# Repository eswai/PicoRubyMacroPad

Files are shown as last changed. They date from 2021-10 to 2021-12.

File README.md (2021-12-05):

# PicoRuby Macropad

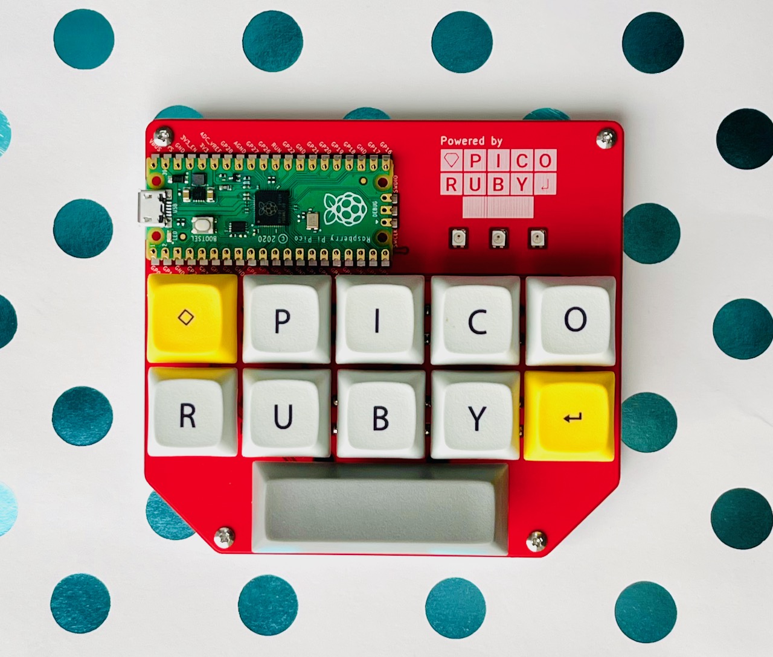
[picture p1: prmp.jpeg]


#  BOM

|Name | Part number|Quantity|
|---|-----|-----|
| MCU | Raspberry Pi Pico | 1|
| Pin header | 20pin | 2|
| PCB | PicoRubyMacroPad_PCB | 1|
| Bottom plate | PicoRubyMacroPad_Plate | 1|
| MX-compaible key switch | 5pins | 11|
| Diode | 1N4148 TH or SMD  | 11|
| Stand-off | M2 L5.5mm or longer | 4|
| Screw | M2 L4mm | 8|
| Keycap | 1U | 10|
| Keycap | 2.75U | 1|
| PCB Stabilizer | 2U | 1|
| LED | SK6812MINI-E | 3|
| Adhesive rubber feet | Dia.9mm or smaller | 4|

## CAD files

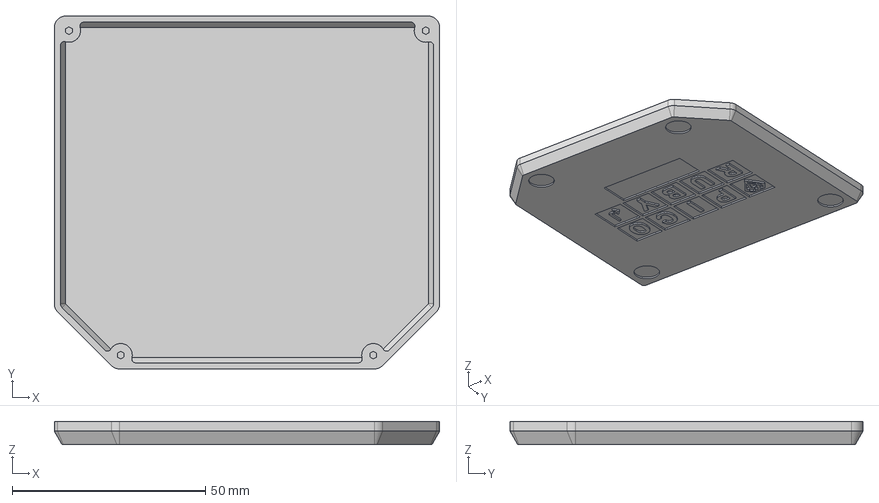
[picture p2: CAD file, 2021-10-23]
PicoRubyMacroPad_case.step
99.8 x 91.4 x 6.00 mm

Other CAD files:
PicoRubyMacroPad_case.f3z

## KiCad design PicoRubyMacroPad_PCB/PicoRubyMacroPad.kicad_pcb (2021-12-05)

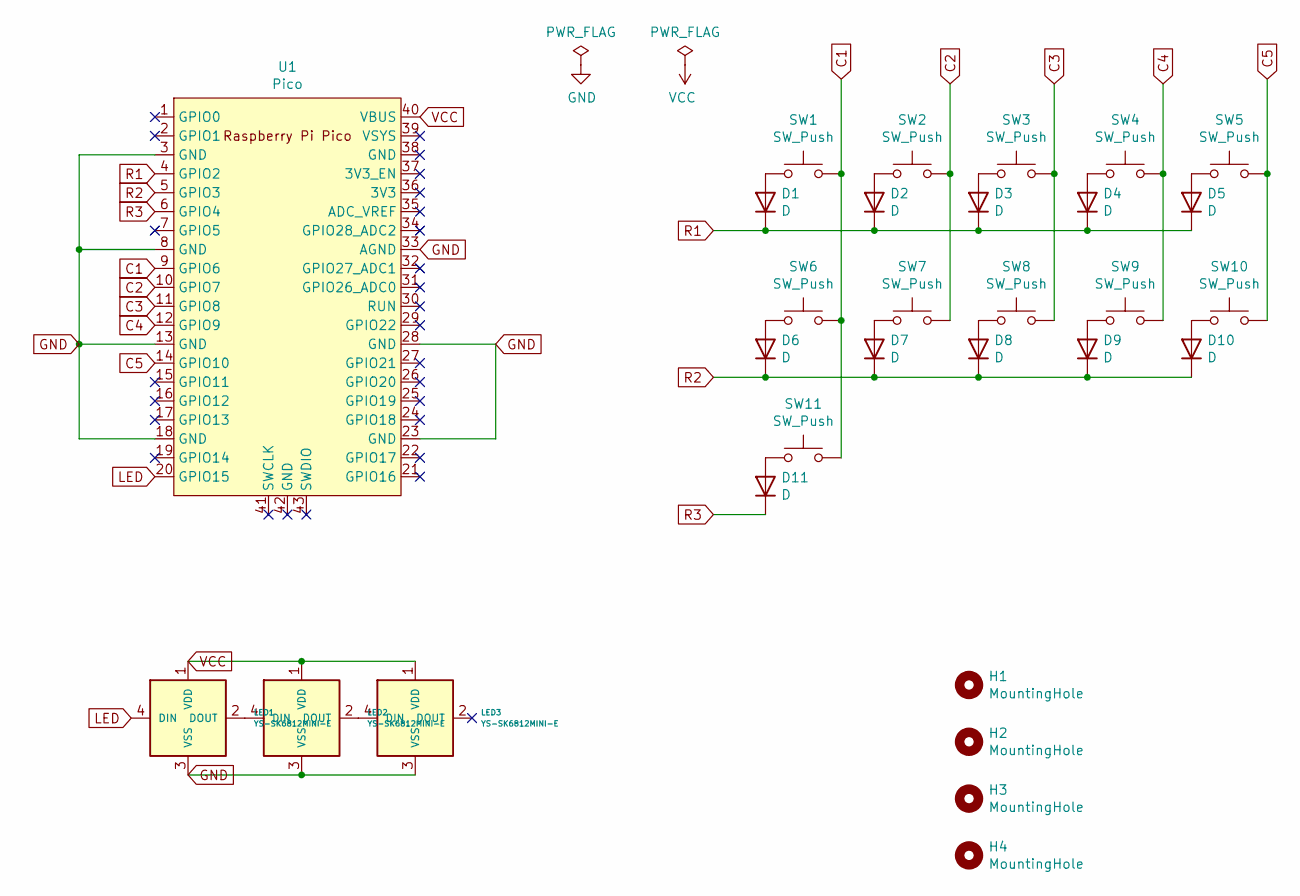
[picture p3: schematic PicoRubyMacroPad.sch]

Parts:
D1, D2, D3, D4, D5, D6, D7, D8, D9, D10, D11: D; D3_TH_SMD_v2
H1, H2, H3, H4: MountingHole; MountingHole_2.2mm_M2
LED1, LED2, LED3: YS-SK6812MINI-E
SW1, SW2, SW3, SW4, SW5, SW6, SW7, SW8, SW9, SW10: SW_Push; MXOnly-1U-NoLED
SW11: SW_Push; MXOnly-2.75U-ReversedStabilizers-NoLED
U1: Pico; RPi_Pico_SMD_TH

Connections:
C1: SW1.2, SW6.2, SW11.2, U1.9 (GPIO6)
C2: SW2.2, SW7.2, U1.10 (GPIO7)
C3: SW3.2, SW8.2, U1.11 (GPIO8)
C4: SW4.2, SW9.2, U1.12 (GPIO9)
C5: SW5.2, SW10.2, U1.14 (GPIO10)
GND: LED1.3 (VSS), LED2.3 (VSS), LED3.3 (VSS), U1.3 (GND), U1.8 (GND), U1.13 (GND), U1.18 (GND), U1.23 (GND), U1.28 (GND), U1.33 (AGND)
LED: LED1.4 (DIN), U1.20 (GPIO15)
unnamed: D1.2 (A), SW1.1
unnamed: D2.2 (A), SW2.1
unnamed: D3.2 (A), SW3.1
unnamed: D4.2 (A), SW4.1
unnamed: D5.2 (A), SW5.1
unnamed: D6.2 (A), SW6.1
unnamed: D7.2 (A), SW7.1
unnamed: D8.2 (A), SW8.1
unnamed: D9.2 (A), SW9.1
unnamed: D10.2 (A), SW10.1
unnamed: D11.2 (A), SW11.1
unnamed: LED1.2 (DOUT), LED2.4 (DIN)
unnamed: LED2.2 (DOUT), LED3.4 (DIN)
R1: D1.1 (K), D2.1 (K), D3.1 (K), D4.1 (K), D5.1 (K), U1.4 (GPIO2)
R2: D6.1 (K), D7.1 (K), D8.1 (K), D9.1 (K), D10.1 (K), U1.5 (GPIO3)
R3: D11.1 (K), U1.6 (GPIO4)
VCC: LED1.1 (VDD), LED2.1 (VDD), LED3.1 (VDD), U1.40 (VBUS)

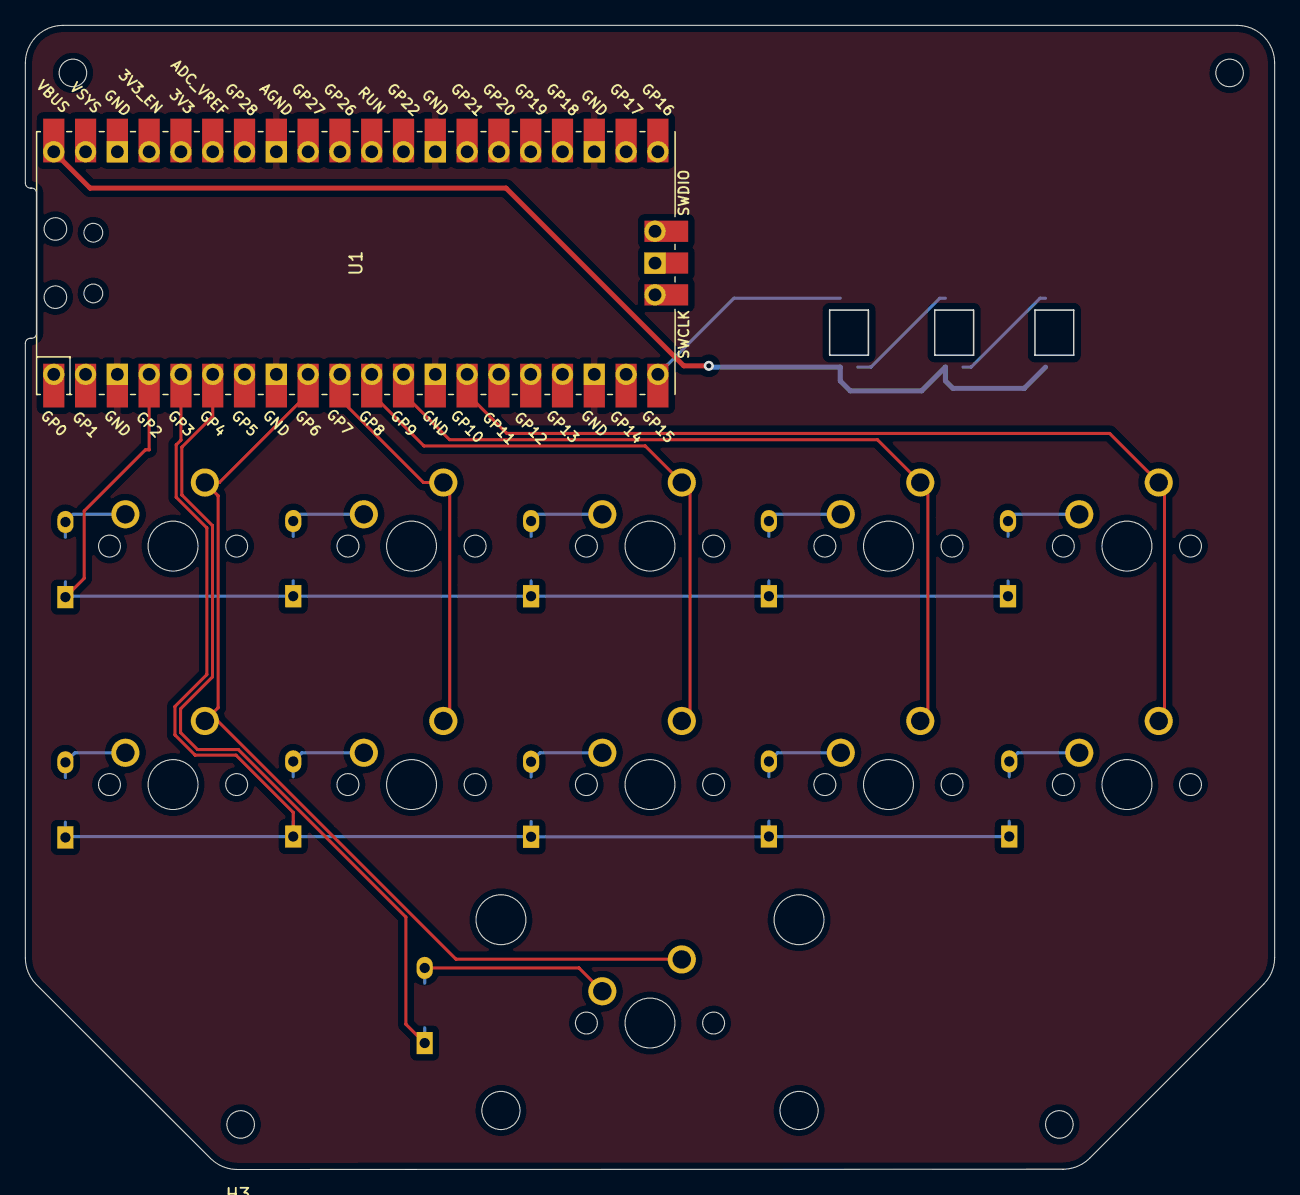
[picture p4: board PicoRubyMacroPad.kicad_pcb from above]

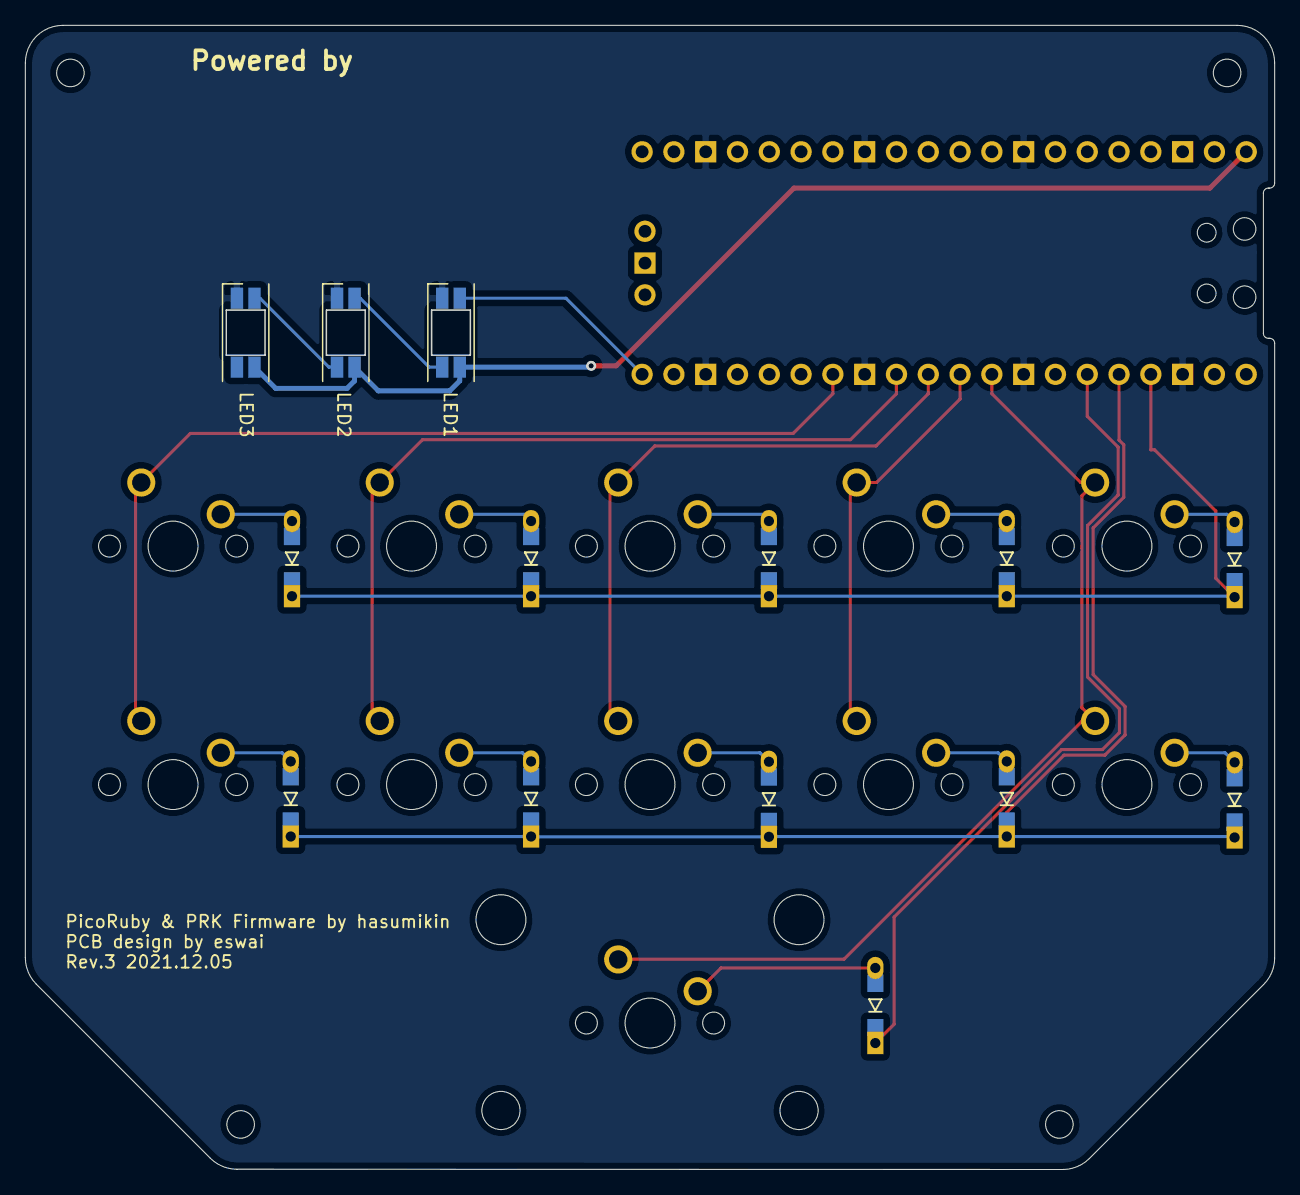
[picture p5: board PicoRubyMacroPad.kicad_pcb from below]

Board: 2 copper layers, 99.8 x 91.4 mm, 30 parts (14 on the bottom side), 24 nets.

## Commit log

2021-10-23 PCB & Plate
    [PicoRubyMacroPad-B_Cu.gbr, PicoRubyMacroPad-B_Mask.gbr, PicoRubyMacroPad-B_Paste.gbr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]
2021-12-05 A diode added for SW11
    [PicoRubyMacroPad-B_Cu.gbr, PicoRubyMacroPad-B_Mask.gbr, PicoRubyMacroPad-B_Paste.gbr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]
2021-12-05 A diode added
